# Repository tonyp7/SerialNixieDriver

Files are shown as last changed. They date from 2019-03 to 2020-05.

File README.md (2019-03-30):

# Serial Nixie Driver
This is the repository for the Arduino library that allows easy control of an IN-12 soviet era single tube or a daisy chain of tubes.

Serial Nixie Driver Demo (http://www.youtube.com/watch?v=PmeA9wflar4 "Youtube Demo")

# How to Install

1. [Download the library](https://github.com/tonyp7/SerialNixieDriver/releases/download/v1.0.0/SerialNixieDriver-v1.0.0.zip)
2. Start Arduino
3. Click on "Sketch/Include Library/Add .ZIP Library..."
4. Select the zip file you have downloaded
5. It's ready! You can now select sample codes using "File/Examples/SerialNixieDriver" or start making your own project!

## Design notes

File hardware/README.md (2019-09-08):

These subfolders contain everything you need to build a serial nixie driver board.

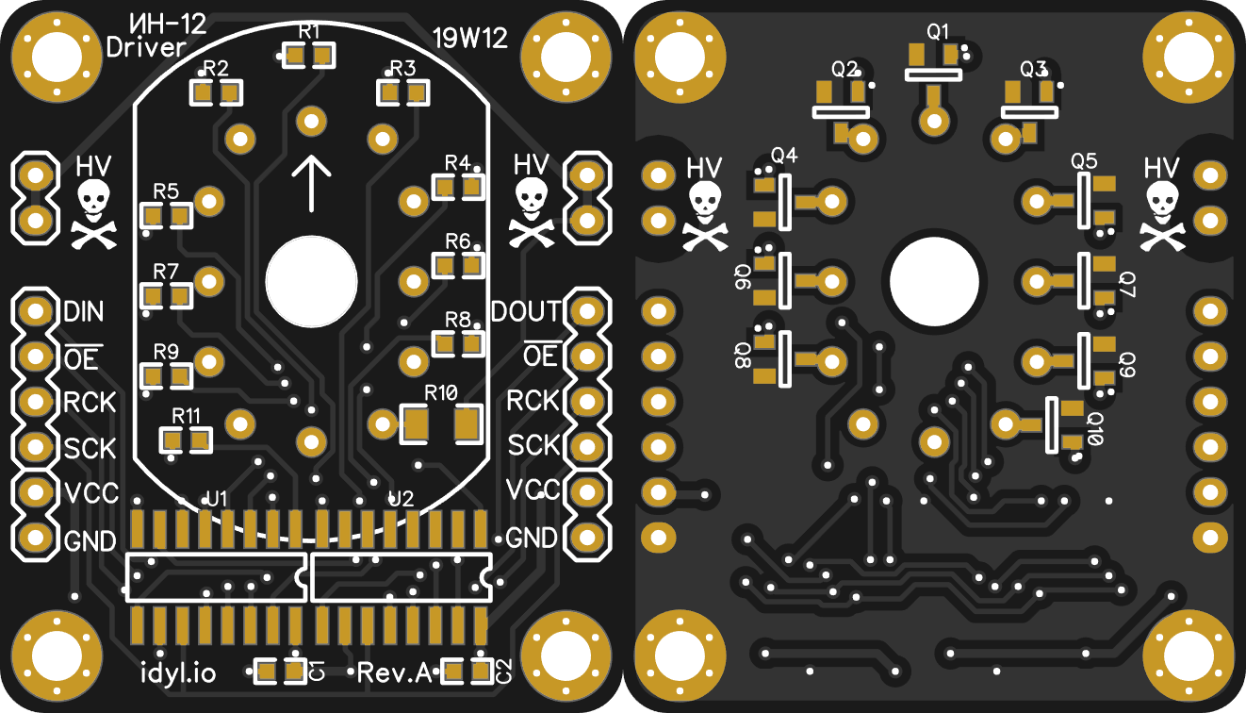
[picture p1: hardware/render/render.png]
PCB Render


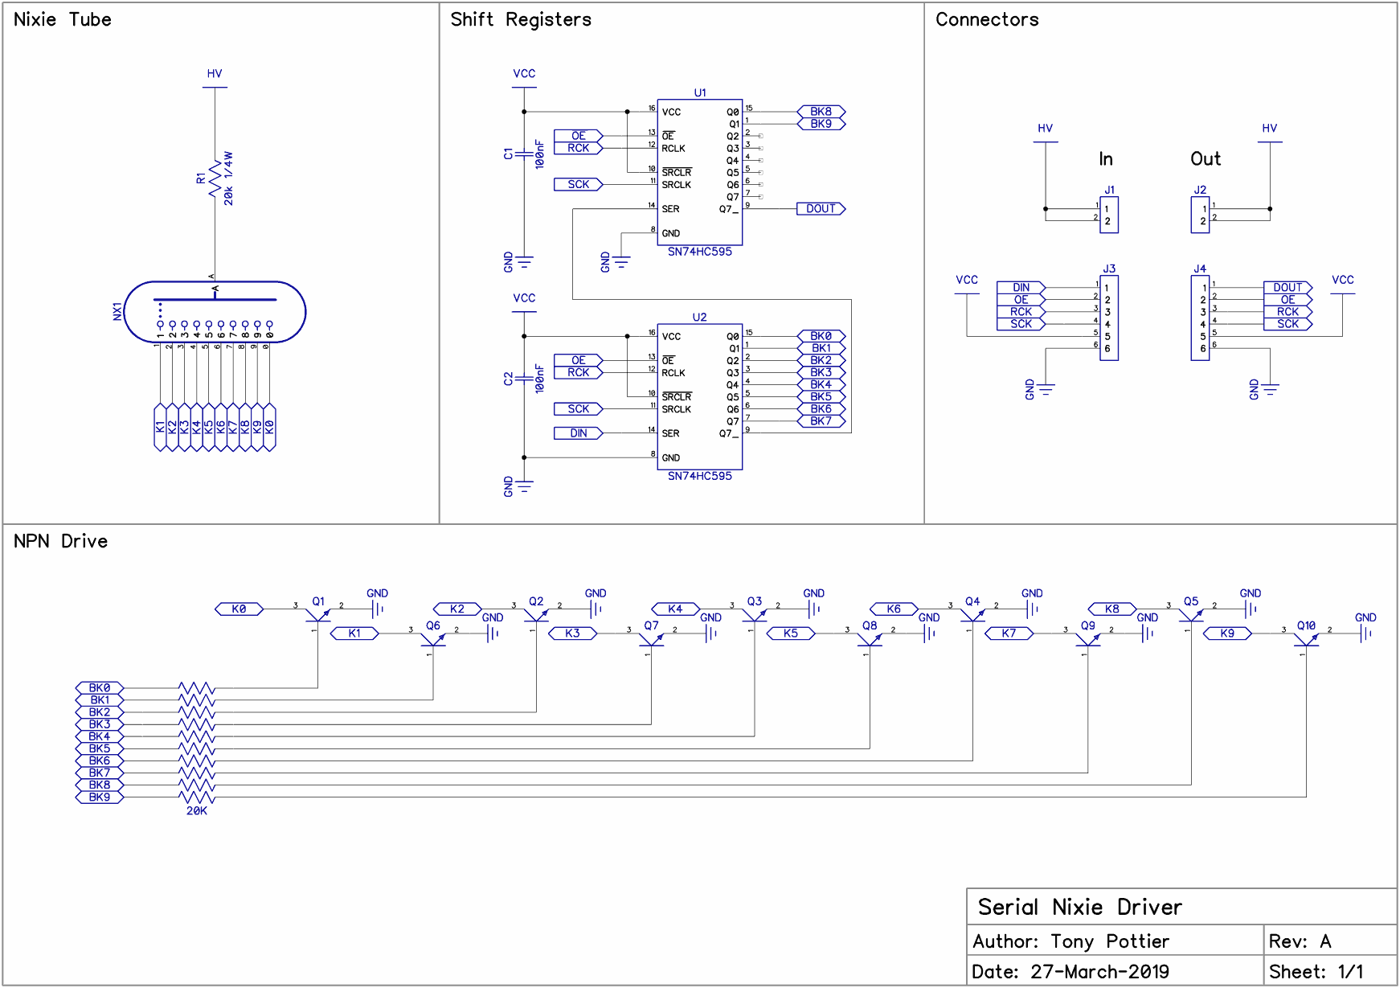
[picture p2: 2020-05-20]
hardware/schematics/serial-nixie-driver-schematics.png

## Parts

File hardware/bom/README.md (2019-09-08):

| Ref Desc | Quantity | Manufacturer | Manufacturer Part Number | Description | Package | Type | Comment |
| --- | --- | --- | --- | --- | --- | ---- | --- |
| C1, C2 | 2 | Yageo | CC0603KRX7R9BB104 | 0.1µF ±10% 50V MLCC X7R 0603 | 0603 | SMD |  |
| R10 | 1 | Yageo | RC1206FR-0720KL | Resistor SMD 20K 1% 1/4W 1206 | 1206 | SMD |  |
| R1, R2, R3, R4, R5, R6, R7, R8, R9, R11 | 10 | Yageo | RC0603FR-0720KL | Resistor SMD 20K 1% 1/10W 0603 | 0603 | SMD |  |
| U1, U2 | 2 | Texas Instruments | SN74HC595DR | Shift Registers 8-Bit Shift Registers With 3-State Output | SOP-16 | SMD | Any SOP 74595 will do. TI is unnecessarily expensive but quoted here for simplicity. |
| Q1, Q2, Q3, Q4, Q5, Q6, Q7, Q8, Q9, Q10 | 10 | On Semiconductors | MMBTA42 | Bipolar Transistors - BJT 500mA 300V NPN | SOT-23-3 | SMD | Extremely common transistor that can be found with many different manufacturers |

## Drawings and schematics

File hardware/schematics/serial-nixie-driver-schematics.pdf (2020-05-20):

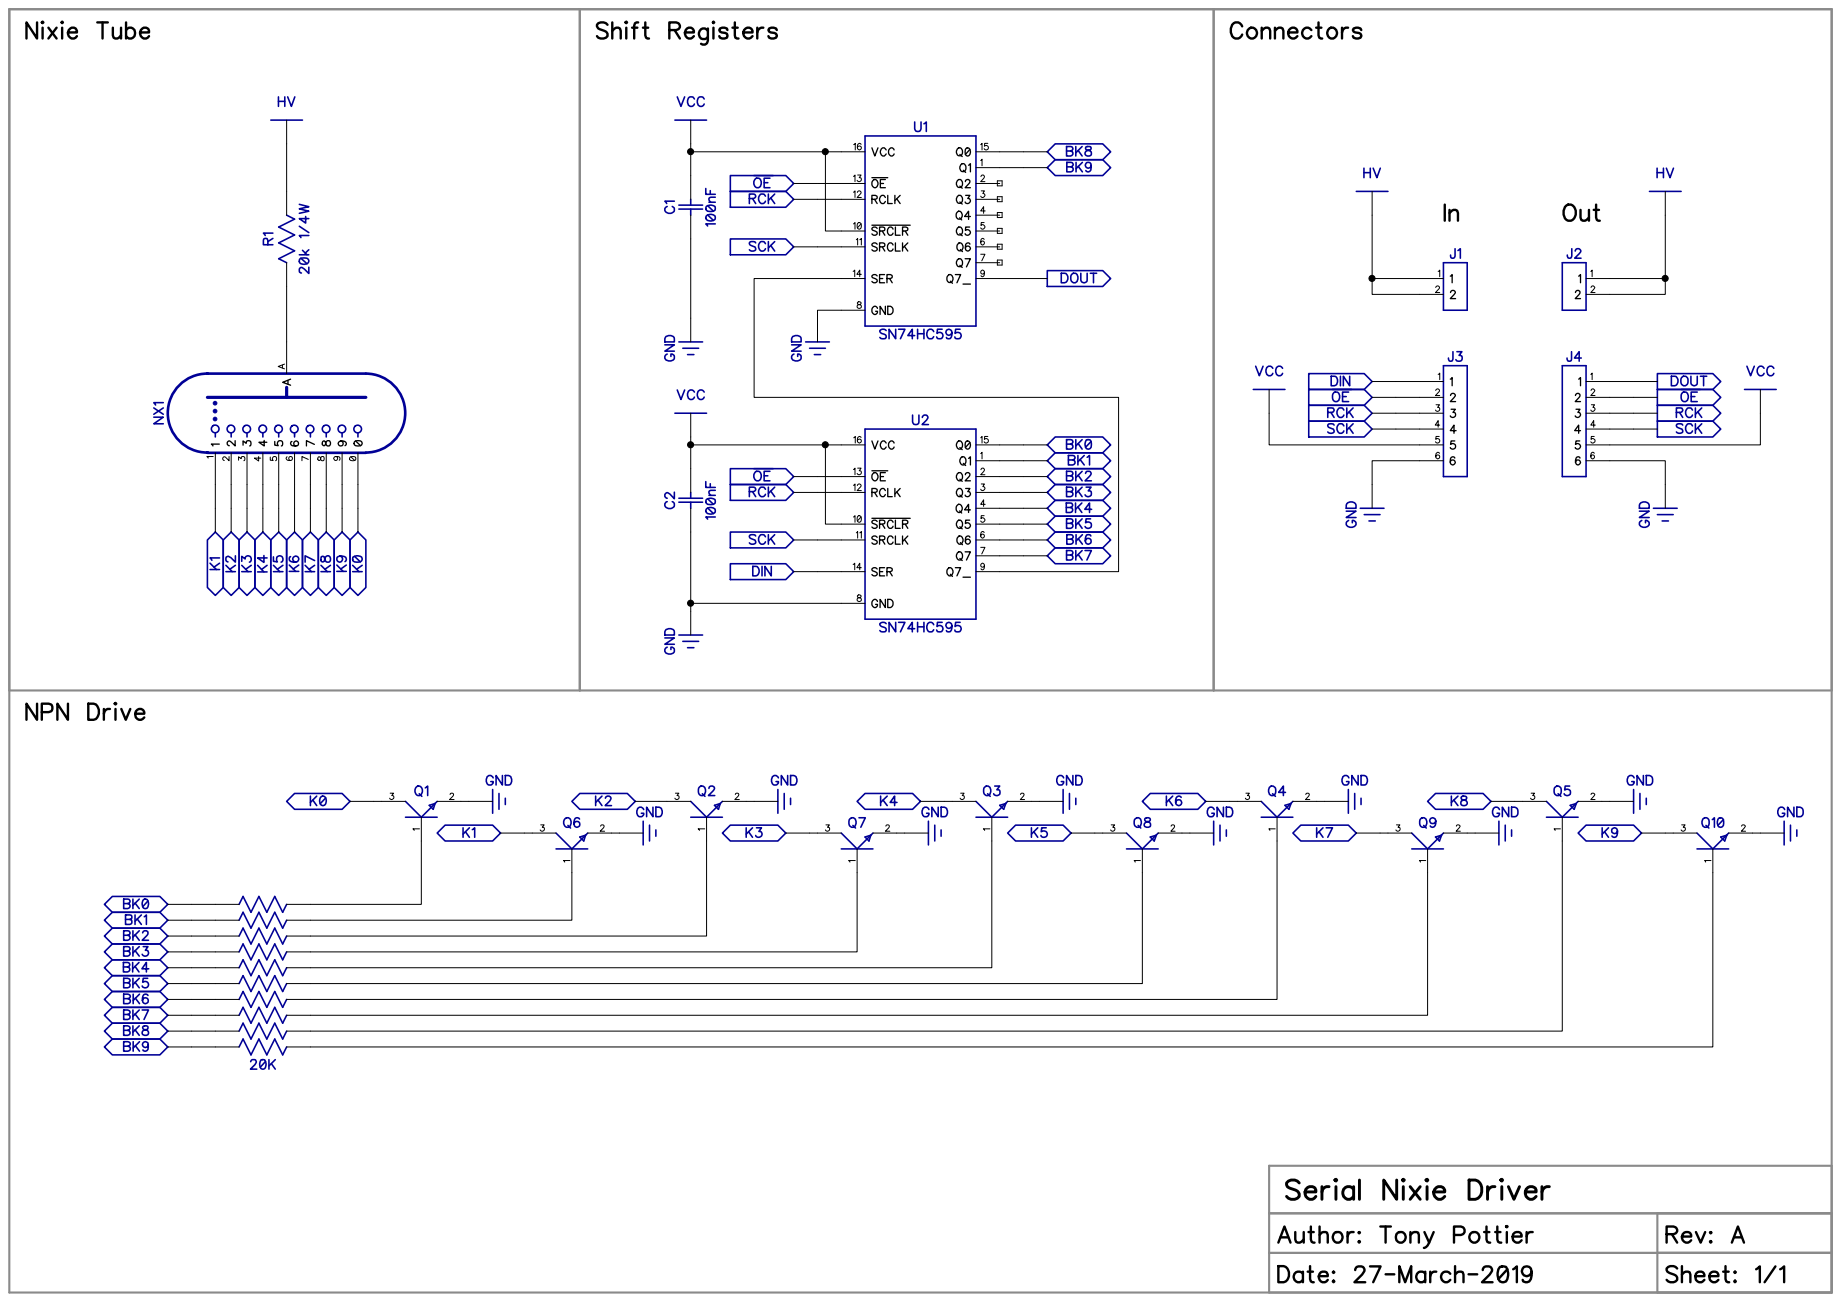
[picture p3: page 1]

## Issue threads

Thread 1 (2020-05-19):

Schematic error

fewi, 2020-05-19:
Hi,
I think pin 10 at the 74HC595's should be connected to VCC or am I'm wrong?

tonyp7, 2020-05-20:
You are absolutely right and it’s a mistake that’s not on the PCB — just the schematics. Thank you for notifying I’ll update ASAP!

Closed 2020-05-20.

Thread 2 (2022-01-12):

Adding dot handling

krupaw2, 2022-01-12:
First of all, thank you very much for the project.

How to modify the library to be able to handle the power supply of an additional channel on the second 74HC595 - Q2 (QC, pin 2)?

I created a similar module, but additionally I placed a neon lamp on it next to a nixi lamp - controlled by the U2 Q2 output.

I would like it to work like this:

// Array used to hold our numbers that will be displayed on the tube
uint8_t data [] = {6, 7, 8, 9};
dots [] = {0,1,1,0}

or something similar:
date [] = {6, 7d, 8d, 9};

The number and the dot must be able to glow together on one module.

I hope I described it well :)

Thanks in advance for any help.

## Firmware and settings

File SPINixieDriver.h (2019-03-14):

/*
Copyright (c) 2019 Tony Pottier

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
@file SPINixieDriver.h
@author Tony Pottier
@brief Arduino library to easily communicated with daisy-chained Nixie tubes.

@see https://idyl.io
@see https://github.com/tonyp7/SPINixieDriver
*/


#ifndef SPINixieDriver_h
#define SPINixieDriver_h

#include <SPI.h>

class SPINixieDriver {
  public:
	SPINixieDriver();
	~SPINixieDriver();
	
	/** @brief Initialize the driver
	*	this should be called in the "setup" part of an Arduino program or outside a loop otherwise.
	*	If hardwareSPI is set to true, the pins specified must be the correct SPI pins of the board being used.
	*	Output Enable is optional and can be set to 0 if not used.
	*	@param rckPin The pin used as a "chip select". Technically the latch register clock.
	*	@param clkPin The pin used for serial clock.
	*	@param dataPin The pin used to transmit data. In the case of hardware SPI this is the MOSI pin.
	*	@param useHardwareSPI If set to true, Arduino SPI library will be used. Otherwise, software serial will be used via the shiftOut function.
	*/
	void begin( int rckPin, int clkPin, int dataPin, int outputEnablePin = 0, bool useHardwareSPI = true);
	
	
	/** @brief Enable/disable output 
	*	Please note that as Output Enable pin uses reverse logic, setting "true" will actually pull the output enable pin LOW.
	*/
	void outputEnable( bool value );
	
	/** @brief kills the driver. If software serial is used this servers no purpose */
	void end();
	
	/** @brief Sends an array of data over daisy-chained nixie tube
	*	@param data an array containing numbers to display
	*/
	void send(const uint8_t *data);
	
	/** @brief Sends a single digit over to a nixie tube
	*	@param data the digit value to display
	*/
	void send(const uint8_t data);

  private:
	bool _useHardwareSPI = true;
	int _rckPin = 0;
	int _clkPin = 0;
	int _dataPin = 0;
	int _outputEnablePin = 0;
	uint16_t decode(uint8_t digit);
};
#endif

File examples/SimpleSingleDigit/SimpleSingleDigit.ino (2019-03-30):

#include <SerialNixieDriver.h>

/**
 SimpleSingleDigit

 This example shows a basic counter on a single Nixie Tube

 For broad compatibility; this is using software serial.

 Copyright (c) 2019 Tony Pottier, Under the MIT License
 @see https://github.com/tonyp7/SerialNixieDriver
 */


/**
 * Please plug the following pin:
 *  Pin 10 to the RCK pin on the board
 *  Pin 13 to the SCK pin on the board
 *  Pin 11 to the DIN (data in) pin on the board
 *  Output Enable should be tied to Ground
 */
int rckPin = 10;
int sckPin = 13;
int dataPin = 11;

SerialNixieDriver driver;


void setup(){
  // Setup as software serial, no output enable pin
  driver.begin(rckPin, sckPin, dataPin, 0, false);
}

void loop(){

  // Count to 9 and mark a pause at the end. 
  for (uint8_t i = 0; i < 10; i++) {
    driver.send(i);
    delay(300);
    if(i==9) delay(700);
  }
  
}

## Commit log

2019-03-14 implemented soft driver
2019-03-25 rename SPI Nixie Driver to Serial Nixie Driver
2019-03-30 added daisy chain example
2019-09-08 open source hardware added
    [SerialNixieDriver.Board.gbr, SerialNixieDriver.BoardOutline.gbr, SerialNixieDriver.Bottom.gbr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]
2019-09-08 added bom
2019-09-08 moved bom under hardware
2019-09-08 README.md
    These subfolders contain everything you need to build your own serial nixie driver.
